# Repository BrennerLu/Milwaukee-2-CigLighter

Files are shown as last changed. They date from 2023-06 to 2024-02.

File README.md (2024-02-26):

# MilwaukeeM18-2-CarCigaretteLighter

There will be a redesign in the near future using the findings of [Tool Scientist](https://www.youtube.com/watch?v=q7spzrIbdKY). By using the official M18 battery protocol, the design will be more reliable while reducing cost and complexity.

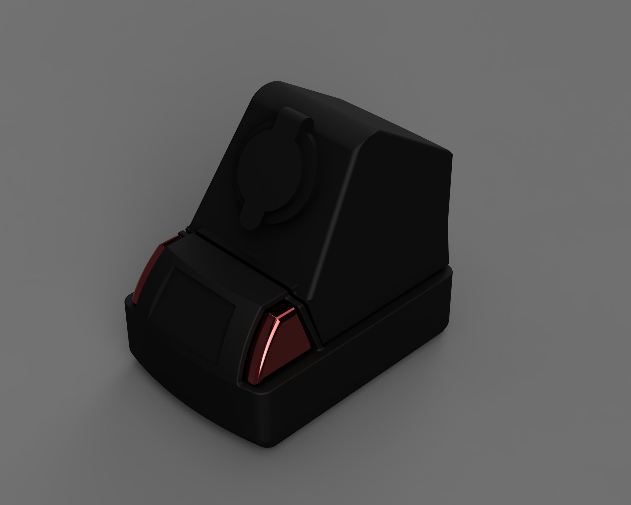
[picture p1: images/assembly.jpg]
assembly


## Description

A small device compatible with the Milwaukee M18 range of batteries. It contains an undervoltage lockout as well as a buck converter that delivers 14 volts at 15 amps to a cigarette lighter socket found in most cars. It can be used to power car-ready devices such as USB-PD chargers, camping fridges and inverters.

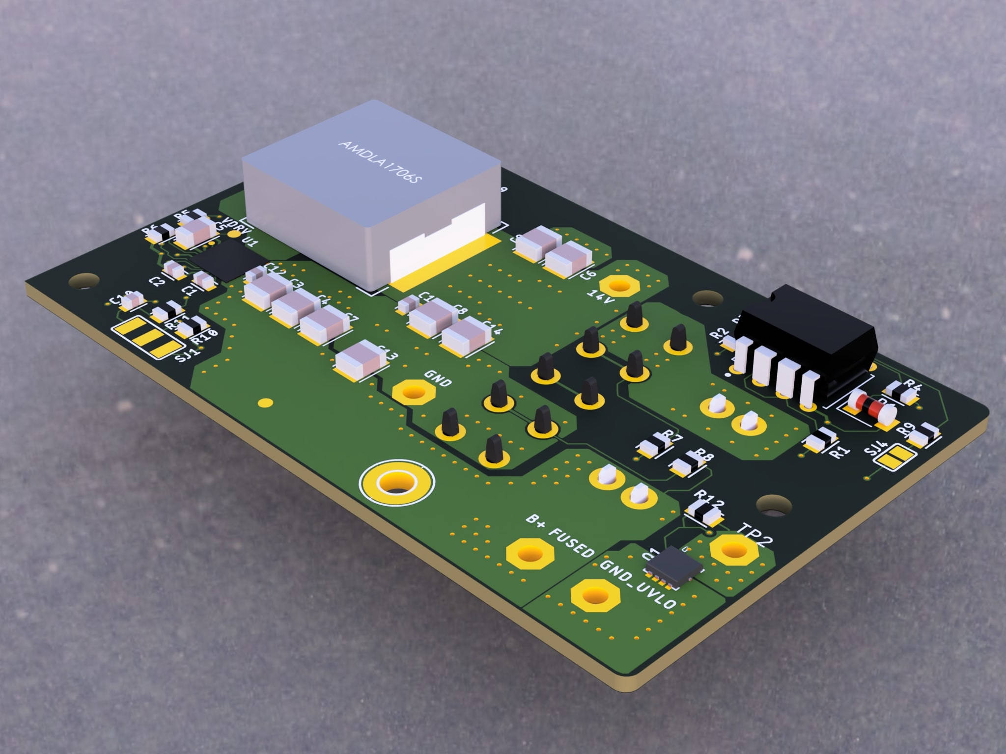
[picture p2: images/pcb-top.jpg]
pcb_top


## Features

- Outputs clean 14V / 15A DC
- Snaps directly into Milwaukee M18 batteries
- Maximum current reduction for small battery sizes such as 2.0Ah
- Two stage over current protection
  - Smooth overcurrent protection by reducing the duty cycle of the buck converter
  - Short-circuit protection via LP mini-blade fuse (commonly found in modern vehicles)
- Undervoltage lockout at 15.5V

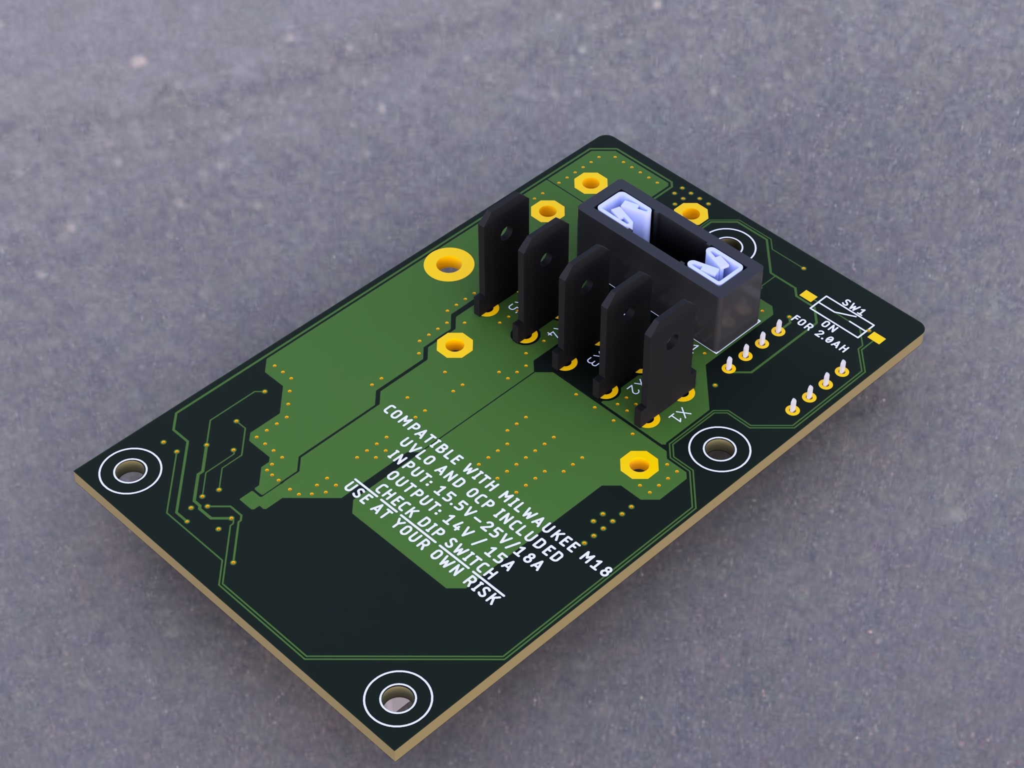
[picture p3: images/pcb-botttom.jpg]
pcb_bottom


## Thanks to
- [oxullo](https://github.com/oxullo) for providing the CAM jobs, design rules and ulps used in this project

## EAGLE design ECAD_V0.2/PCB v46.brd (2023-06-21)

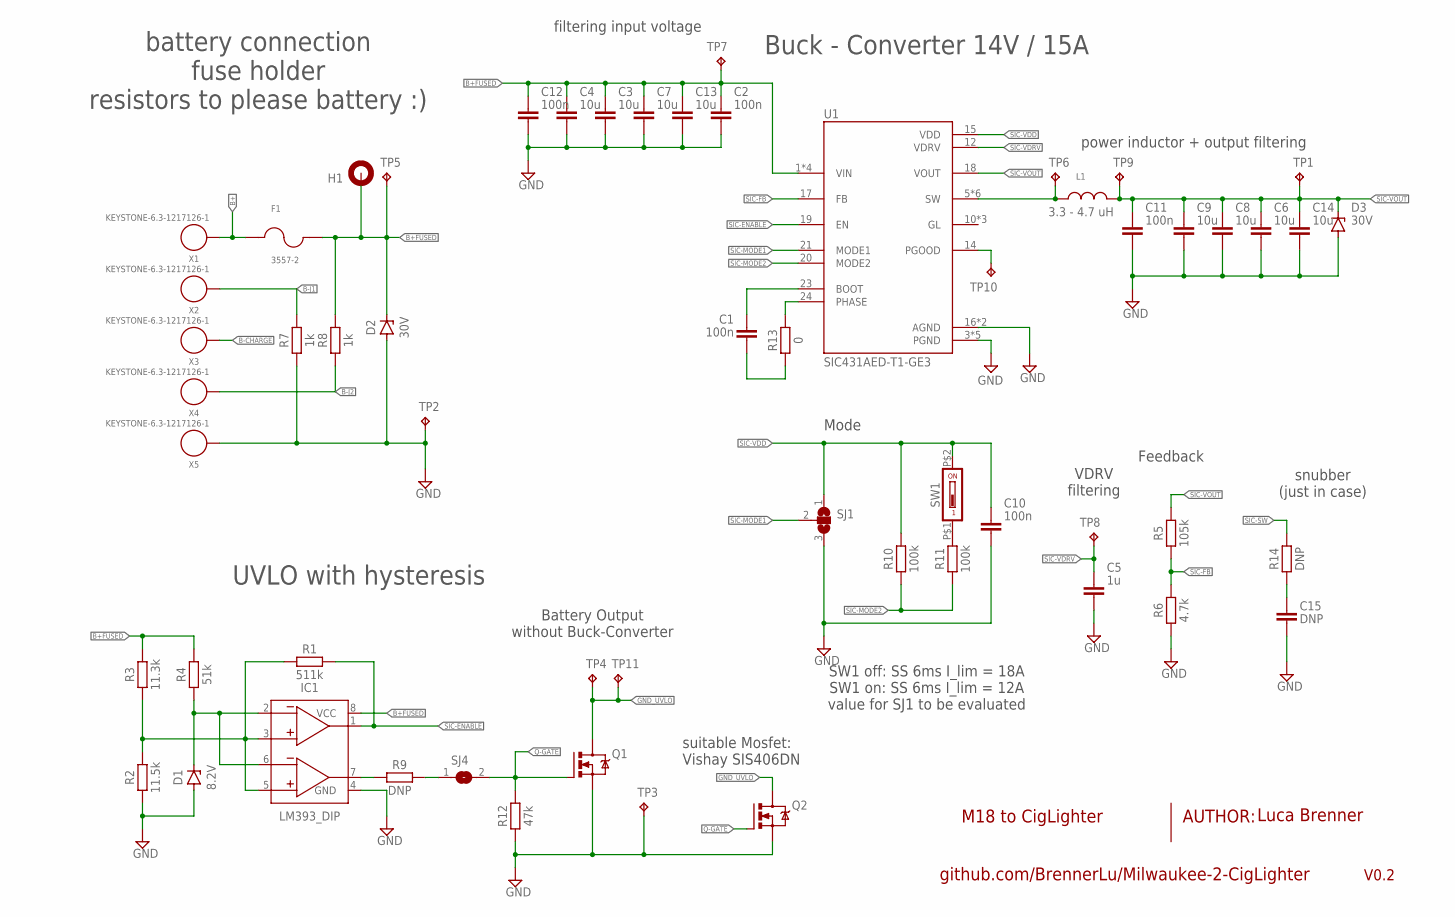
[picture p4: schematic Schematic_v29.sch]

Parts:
C1, C2, C10, C11, C12: 100n; CAPC1608X85
C3, C4, C6, C7, C8, C9, C13, C14: 10u; CAPC3225X135
C5: 1u; CAPC3216X135
C15: DNP; CAPC1608X85
D1: 8.2V; DIOMELF3516
D2, D3: 30V; DIOM5336X265N
F1: 3557-2; FUSE_3557-2
H1: MOUNT-PAD-ROUND2.8; 2,8-PAD
IC1: LM393_DIP; DIP826W53P254L959H508Q8B
L1: 3.3 - 4.7 uH; AMDLA1707S-3R3MT-FP
Q1, Q2: VISHAY-SIS406DN; POWERPAK-1212-8-SINGLE
R1: 511k; RESC2012X65
R2: 11.5k; RESC2012X65
R3: 11.3k; RESC2012X65
R4: 51k; RESC2012X65
R5: 105k; RESC2012X65
R6: 4.7k; RESC2012X65
R7, R8: 1k; RESC2012X65
R9: DNP; RESC2012X65
R10, R11: 100k; RESC2012X65
R12: 47k; RESC2012X65
R13: 0; RESC1608X60
R14: DNP; RESC1608X60
SJ1: SJ2WW; SJ_2W
SJ4: SJ
SW1: DS04-254-SMT; DIPSW-SMD-254
TP1, TP2, TP3, TP4, TP5, TP11: TPPAD1-20; P1-20
TP6, TP7, TP8, TP9: TPB1,27; B1,27
TP10: TPTP06R; TP06R
U1: SIC431AED-T1-GE3; REGULATOR_SIC431AED-T1-GE3
X1, X2, X3, X4, X5: KEYSTONE-6.3-1217126-1; KEYSTONE.6.3-1217126-1-FP

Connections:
B+: F1.1_1 (1), F1.1_2 (1), X1.P$1, X1.P$2
B+FUSED: C2.1, C3.1, C4.1, C7.1, C12.1, C13.1, D2.1 (C), F1.2_1 (2), F1.2_2 (2), H1.B2,8, IC1.8 (VCC), R3.2, R4.2, R8.1, TP5.TP, TP7.TP, U1.1 (VIN), U1.2 (VIN), U1.22 (VIN), U1.26 (VIN)
B-CHARGE: X3.P$1, X3.P$2
B-J1: R7.1, X2.P$1, X2.P$2
B-J2: R8.2, X4.P$1, X4.P$2
GND: C2.2, C3.2, C4.2, C5.2, C6.2, C7.2, C8.2, C9.2, C10.2, C11.2, C12.2, C13.2, C14.2, C15.1, D1.2 (A), D2.2 (A), D3.2 (A), IC1.4 (GND), Q1.S1 (S), Q1.S2 (S), Q1.S3 (S), Q2.S1 (S), Q2.S2 (S), Q2.S3 (S), R2.1, R6.1, R7.2, R12.1, SJ1.3, TP2.TP, TP3.TP, U1.3 (PGND), U1.4 (PGND), U1.13 (PGND), U1.16 (AGND), U1.25 (AGND), U1.27_1 (PGND), U1.27_2 (PGND), X5.P$1, X5.P$2
GND_UVLO: Q1.D1 (D), Q1.D2 (D), Q1.D3 (D), Q1.D4 (D), Q1.D-PAD (D), Q2.D1 (D), Q2.D2 (D), Q2.D3 (D), Q2.D4 (D), Q2.D-PAD (D), TP4.TP, TP11.TP
unnamed: R11.2, SW1.P$1 (1)
unnamed: D1.1 (C), IC1.2 (-IN1), IC1.6 (-IN2), R4.1
unnamed: IC1.3 (+IN1), IC1.5 (+IN2), R1.1, R2.2, R3.1
unnamed: IC1.7 (OUT2), R9.1
unnamed: R9.2, SJ4.1
unnamed: TP10.TP, U1.14 (PGOOD)
unnamed: R13.2, U1.24 (PHASE)
unnamed: C15.2, R14.1
Q-GATE: Q1.G, Q2.G, R12.2, SJ4.2
SIC-BOOT: C1.2, U1.23 (BOOT)
SIC-ENABLE: IC1.1 (OUT1), R1.2, U1.19 (EN)
SIC-FB: R5.1, R6.2, U1.17 (FB)
SIC-MODE1: SJ1.2, U1.21 (MODE1)
SIC-MODE2: R10.1, R11.1, U1.20 (MODE2)
SIC-PHASE: C1.1, R13.1
SIC-SW: L1.P$1 (1), R14.2, TP6.TP, U1.5 (SW), U1.6 (SW), U1.7 (SW), U1.8 (SW), U1.9 (SW), U1.9.1 (SW)
SIC-VDD: C10.1, R10.2, SJ1.1, SW1.P$2 (2), U1.15 (VDD)
SIC-VDRV: C5.1, TP8.TP, U1.12 (VDRV)
SIC-VOUT: C6.1, C8.1, C9.1, C11.1, C14.1, D3.1 (C), L1.P$2 (2), R5.2, TP1.TP, TP9.TP, U1.18 (VOUT)

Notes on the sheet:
filtering input voltage
Feedback
Mode
VDRV filtering
battery connection fuse holder resistors to please battery :)
AUTHOR:
UVLO with hysteresis
Battery Output without Buck-Converter
power inductor + output filtering
Buck - Converter 14V / 15A
SW1 off: SS 6ms I_lim = 18A SW1 on: SS 6ms I_lim = 12A value for SJ1 to be evaluated
V0.2
M18 to CigLighter
snubber (just in case)
suitable Mosfet: Vishay SIS406DN

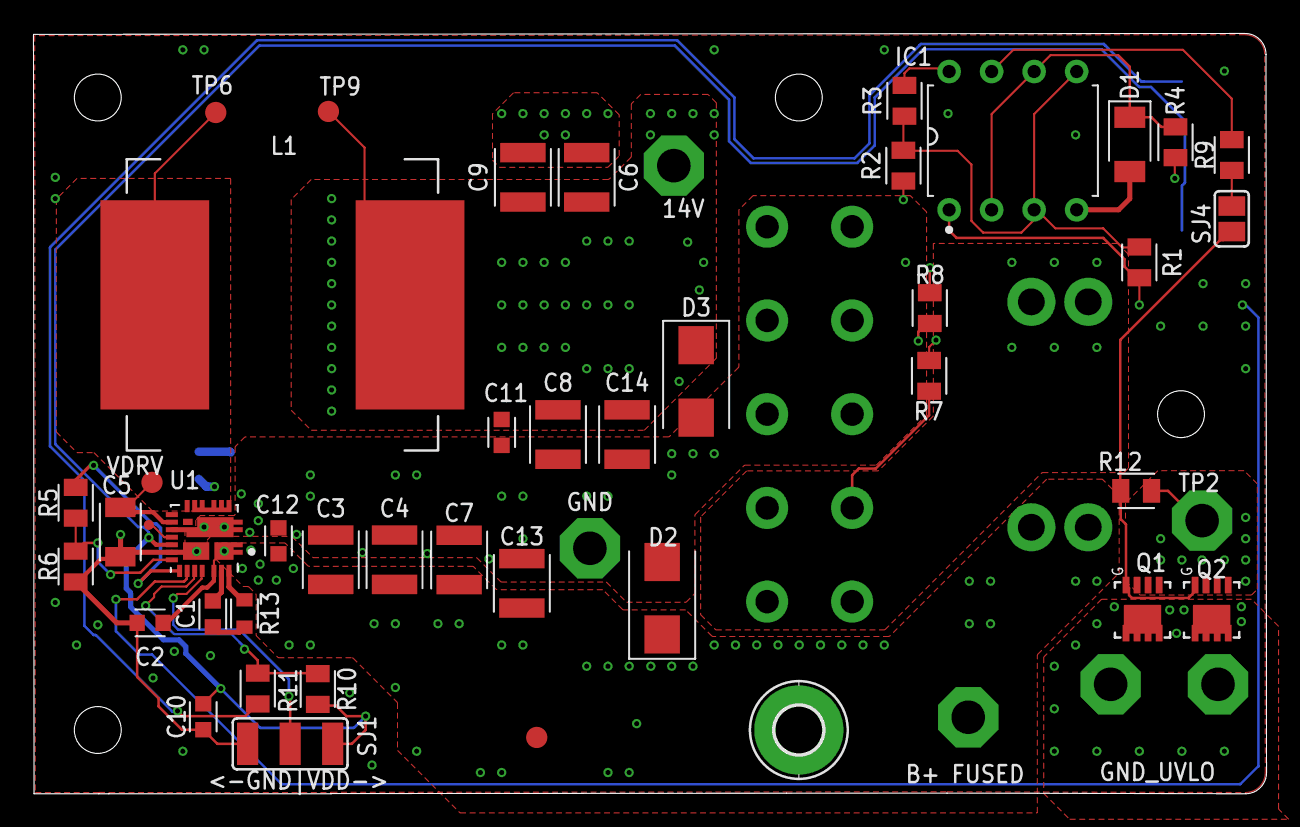
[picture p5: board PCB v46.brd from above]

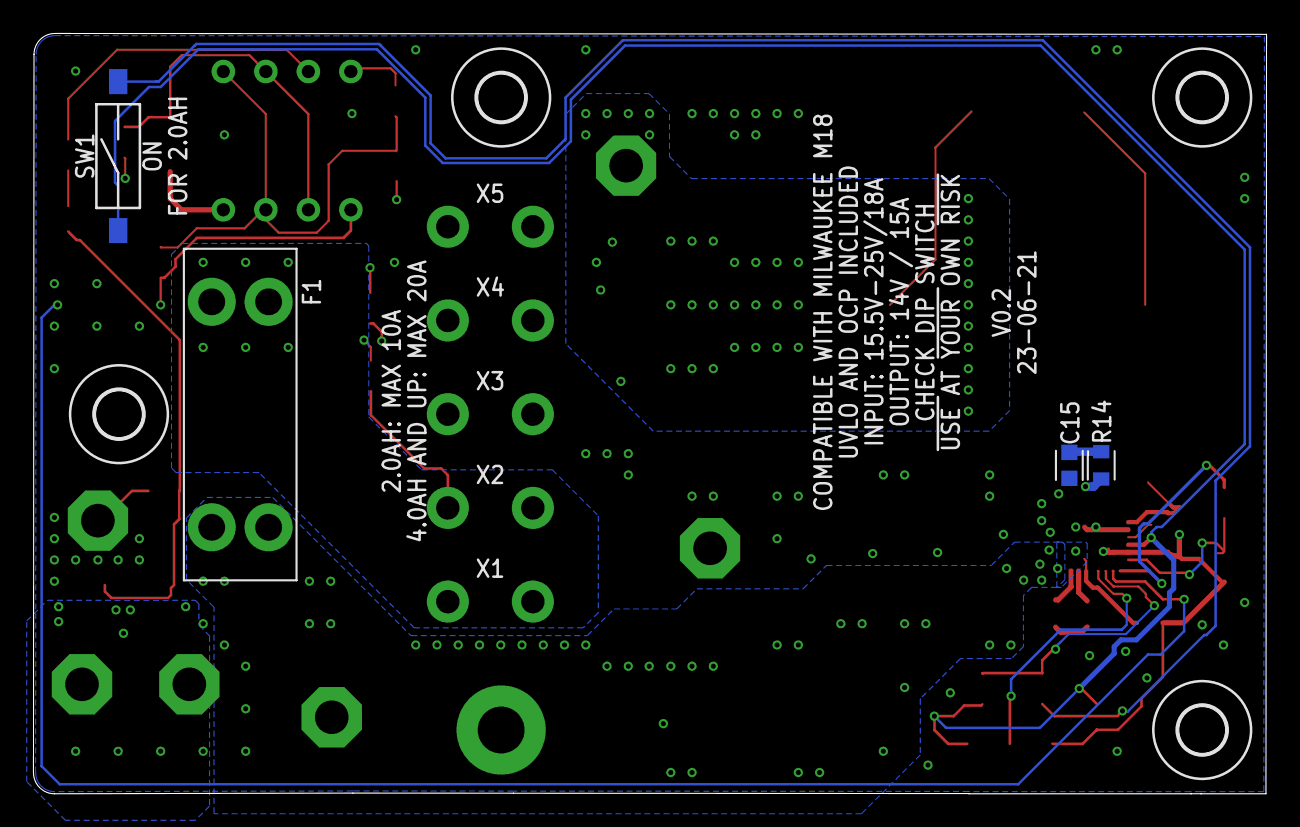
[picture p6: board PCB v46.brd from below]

Board: 4 copper layers, 73.7 x 45.4 mm, 62 parts (13 on the bottom side), 26 nets.

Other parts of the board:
U$1, U$4, U$5, U$6: 2,8

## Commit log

2023-05-18 Added files for production
    [Calculations.xlsx, PCB v36_bom.csv, Schematic.f3d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]
2023-05-18 added schematic for first production pcb
2023-05-18 restructered folders
    [PCB v36_bom.csv, Schematic.f3d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]
2023-05-19 Added Fusion Archive Files
    [Calculations.xlsx]
2023-06-21 New optional mosfets, Thermal Vias under SIC431, minor layout changes
    [Calculations.xlsx, PCB v36_bom.csv, PCB v46.brd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]
